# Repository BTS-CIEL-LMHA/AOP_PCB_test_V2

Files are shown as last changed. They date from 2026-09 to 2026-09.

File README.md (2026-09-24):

Ce PCB a été crée pour expérimenter sur différents montages d'amplificateurs opérationnels.

Le principe est d'utiliser 2 cavaliers pour sélectionner le montage utilisé : un pour l'entrée, l'autre pour la sortie.

2 cavaliers à l'entrée et à la sortie du PCB permettent de court-circuiter les condensateurs de liaison pour obtenir une entrée avec offset (indispensable cf ci-dessous)

ATTENTION : il ne faut pas avoir plusieurs cavaliers sur des sorties au risque de court circuit et de destruction des AOP

(on peut avoir plusieurs cavaliers sur les entrées mais c'est déconseillé et cela peut créer des effets indésirables : injection de tension d'un montage à l'autre)

REMARQUE : Les amplis inverseurs et les filtres passe-haut et passe-bande ne sont pas utilisables car l'entrée + est reliée directement ou par une résistance à la masse (au lieu du point milieu de l'alimentation = masse virtuelle)

Les amplis non inverseurs sont utilisable à condition d'avoir un offset (1/2 alimentation) sur le signal d'entrée.

Il est possible assez facilement de modifier les filtres passe-haut et passe-bande en remplaçant la résistance qui va vers la masse par une résistance qui va vers une masse virtuelle.

Pour les amplis inverseur la connexion à la masse étant directe la modification est plus complexe (couper la connexion à la masse du PCB et installer un fil vers la masse virtuelle).

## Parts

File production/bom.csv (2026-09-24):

Designator | Footprint | Quantity | Value | LCSC Part #
C1, C10, C11, C2, C21, C22, C23, C24, C27, C3, C4, C5, C6 | C_Rect_L11.5mm_W3.6mm_P10.00mm_MKT | 13 | C
C20 | C_Radial_D10.0mm_H12.5mm_P5.00mm | 1 | C
C25, C26 | 1206 | 2 | C
J1, J10, J11, J12, J13, J14, J15, J16, J2, J3, J4, J40, J42, J5, J6, J7, J8, J9 | PinHeader_1x02_P2.54mm_Vertical | 18 | Conn_01x02_Pin
J30 | PinHeader_1x02_P2.54mm_Vertical | 1 | Alim
J31 | PinHeader_1x02_P2.54mm_Vertical | 1 | Pile
J32 | BarrelJack_Wuerth_6941xx301002 | 1 | Barrel_Jack_Switch
J41, J43 | BNC_Amphenol_B6252HB-NPP3G-50_Horizontal | 2 | Conn_Coaxial
R1, R10, R11, R2, R3, R4, R5, R6, R7, R8, R9 | R_Axial_DIN0204_L3.6mm_D1.6mm_P7.62mm_Horizontal | 11 | R_US
R12, R13, R14, R15 | 1206 | 4 | R_US
U1, U2, U3, U4, U5 | DIP-8_W7.62mm_Socket_LongPads | 5 | TL081
U6, U7 | SOIC-8_3.9x4.9mm_P1.27mm | 2 | TL081

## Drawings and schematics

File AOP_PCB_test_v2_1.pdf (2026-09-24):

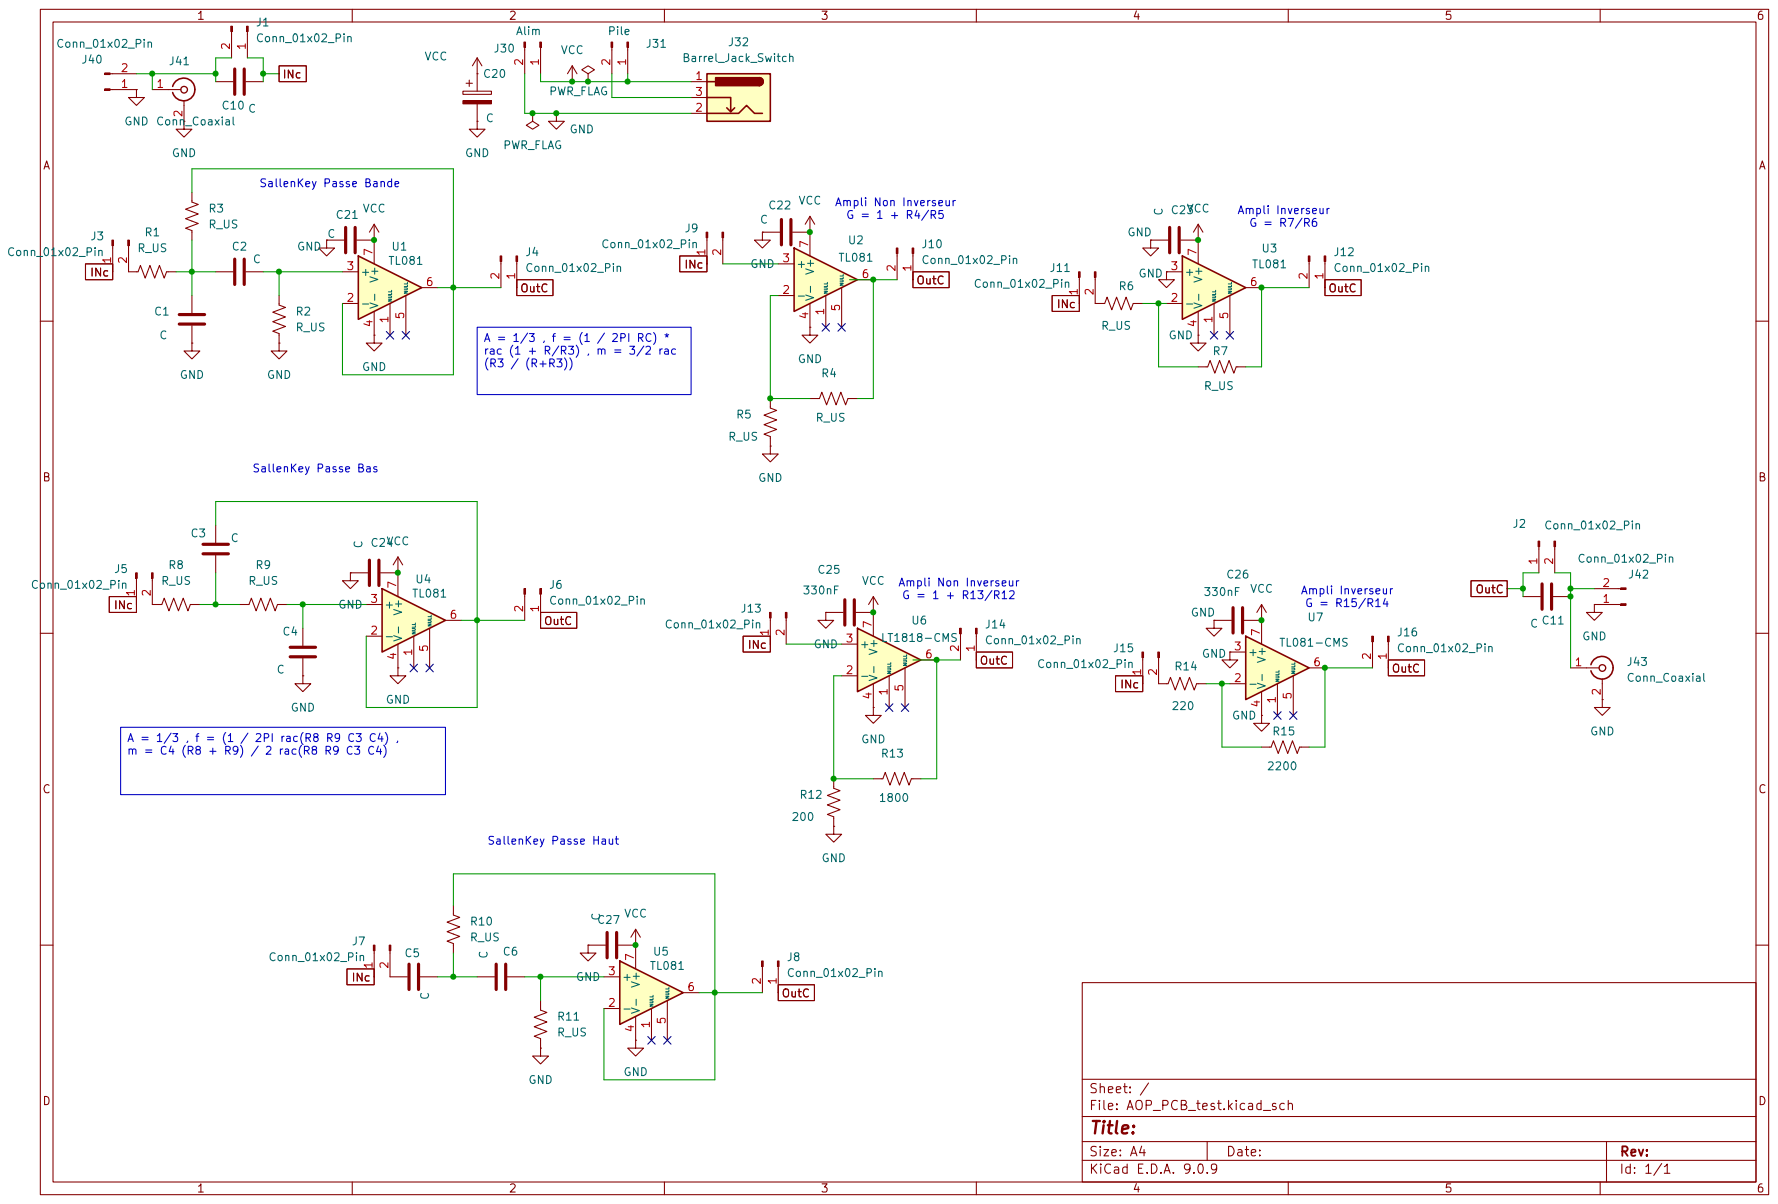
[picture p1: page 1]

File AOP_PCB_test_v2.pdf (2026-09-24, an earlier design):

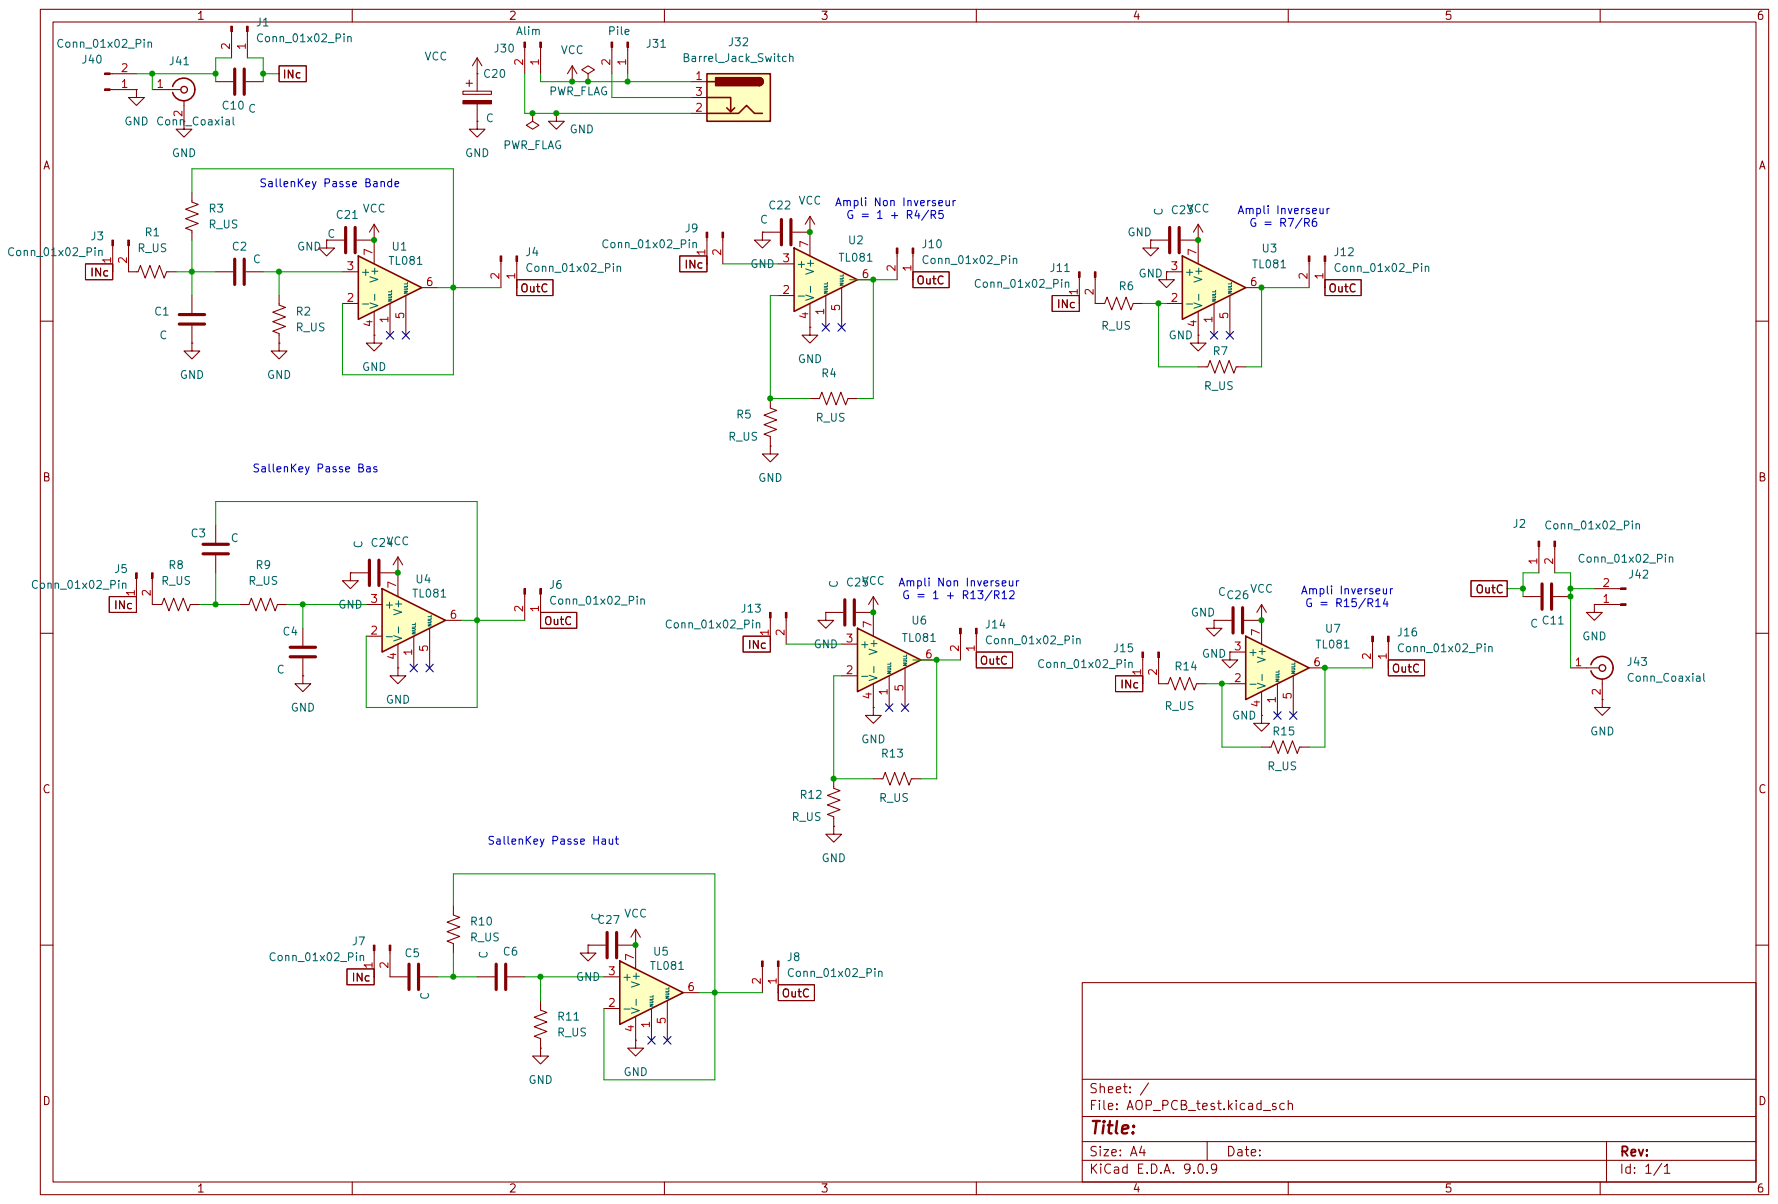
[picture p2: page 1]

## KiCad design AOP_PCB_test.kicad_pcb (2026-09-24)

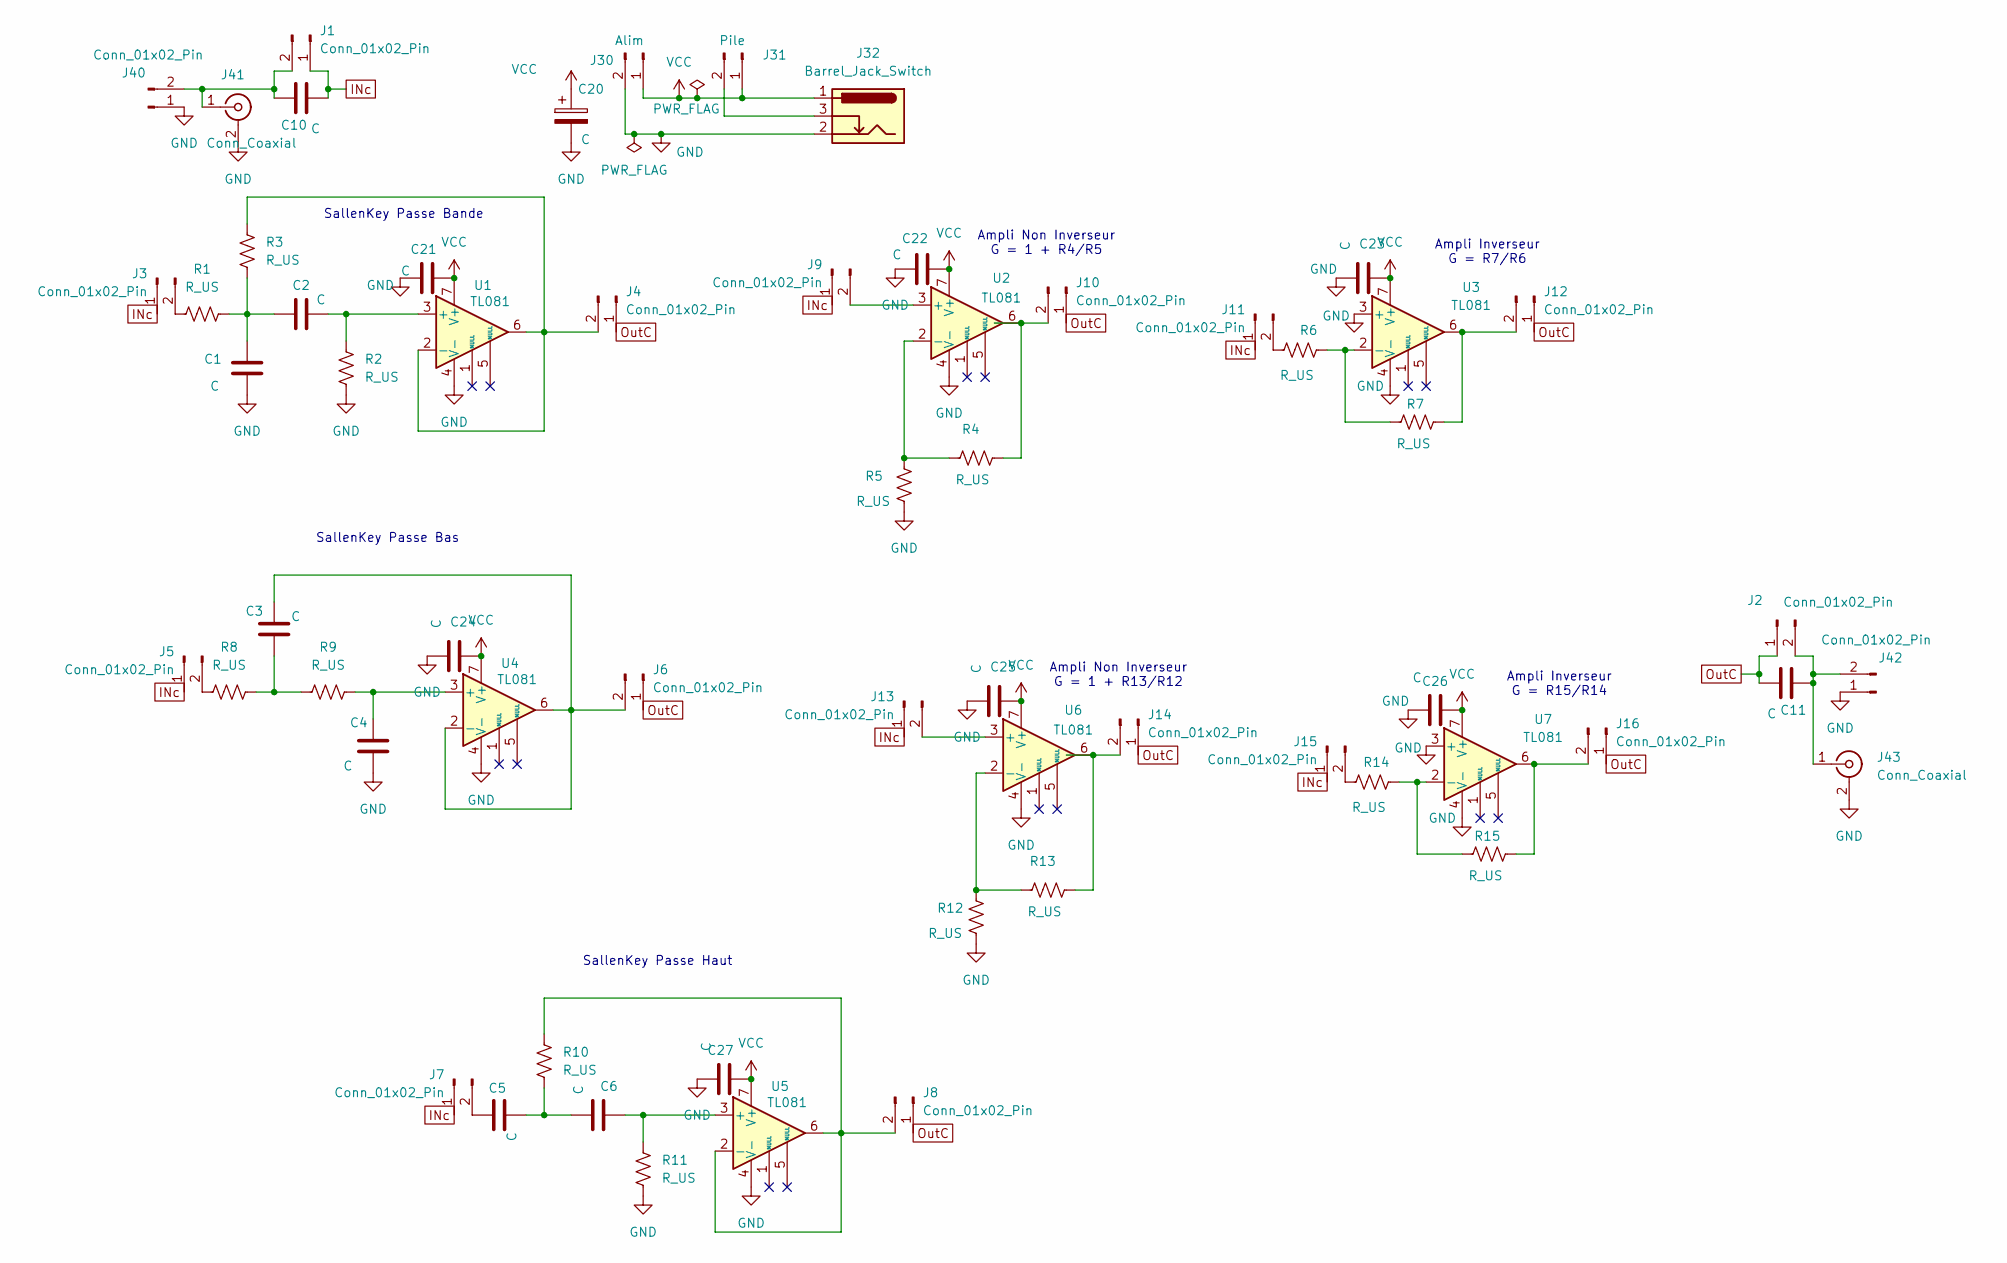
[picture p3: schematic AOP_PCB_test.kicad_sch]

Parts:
C1, C2, C3, C4, C5, C6, C10, C11, C21, C22, C23, C24, C27: C; C_Rect_L11.5mm_W3.6mm_P10.00mm_MKT
C20: C; C_Radial_D10.0mm_H12.5mm_P5.00mm
C25, C26: C; C_1206_3216Metric_Pad1.33x1.80mm_HandSolder
J1, J2, J3, J4, J5, J6, J7, J8, J9, J10, J11, J12, J13, J14, J15, J16, J40, J42: Conn_01x02_Pin; PinHeader_1x02_P2.54mm_Vertical
J30: Alim; PinHeader_1x02_P2.54mm_Vertical
J31: Pile; PinHeader_1x02_P2.54mm_Vertical
J32: Barrel_Jack_Switch; BarrelJack_Wuerth_6941xx301002
J41, J43: Conn_Coaxial; BNC_Amphenol_B6252HB-NPP3G-50_Horizontal
R1, R2, R3, R4, R5, R6, R7, R8, R9, R10, R11: R_US; R_Axial_DIN0204_L3.6mm_D1.6mm_P7.62mm_Horizontal
R12, R13, R14, R15: R_US; R_1206_3216Metric_Pad1.30x1.75mm_HandSolder
U1, U2, U3, U4, U5: TL081; DIP-8_W7.62mm_Socket_LongPads
U6, U7: TL081; SOIC-8_3.9x4.9mm_P1.27mm

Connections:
GND: C1.2, C4.2, C20.2, C21.2, C22.2, C23.2, C24.2, C25.2, C26.2, C27.2, J30.2, J32.2, J40.1, J41.2 (Ext), J42.1, J43.2 (Ext), R2.1, R5.1, R11.2, R12.1, U1.4 (V-), U2.4 (V-), U3.3 (+), U3.4 (V-), U4.4 (V-), U5.4 (V-), U6.4 (V-), U7.3 (+), U7.4 (V-)
INc: C10.1, J1.1, J3.1, J5.1, J7.1, J9.1, J11.1, J13.1, J15.1
unnamed: C1.1, C2.2, R1.1, R3.2
unnamed: C3.2, R8.1, R9.2
unnamed: C5.1, C6.2, R10.1
unnamed: C10.2, J1.2, J40.2, J41.1 (In)
unnamed: C11.2, J2.2, J42.2, J43.1 (In)
unnamed: J3.2, R1.2
unnamed: J4.2, R3.1, U1.2 (-), U1.6
unnamed: J5.2, R8.2
unnamed: C3.1, J6.2, U4.2 (-), U4.6
unnamed: C5.2, J7.2
unnamed: J8.2, R10.2, U5.2 (-), U5.6
unnamed: J9.2, U2.3 (+)
unnamed: J10.2, R4.2, U2.6
unnamed: J11.2, R6.2
unnamed: J12.2, R7.2, U3.6
unnamed: J13.2, U6.3 (+)
unnamed: J14.2, R13.2, U6.6
unnamed: J15.2, R14.2
unnamed: J16.2, R15.2, U7.6
unnamed: J31.2, J32.3
unnamed: C2.1, R2.2, U1.3 (+)
unnamed: R4.1, R5.2, U2.2 (-)
unnamed: R6.1, R7.1, U3.2 (-)
unnamed: C4.1, R9.1, U4.3 (+)
unnamed: C6.1, R11.1, U5.3 (+)
unnamed: R12.2, R13.1, U6.2 (-)
unnamed: R14.1, R15.1, U7.2 (-)
OutC: C11.1, J2.1, J4.1, J6.1, J8.1, J10.1, J12.1, J14.1, J16.1
VCC: C20.1, C21.1, C22.1, C23.1, C24.1, C25.1, C26.1, C27.1, J30.1, J31.1, J32.1, U1.7 (V+), U2.7 (V+), U3.7 (V+), U4.7 (V+), U5.7 (V+), U6.7 (V+), U7.7 (V+)

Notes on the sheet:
Ampli Non Inverseur G = 1 + R4/R5
SallenKey Passe Bas
Ampli Non Inverseur G = 1 + R13/R12
Ampli Inverseur G = R15/R14
SallenKey Passe Haut
Ampli Inverseur G = R7/R6
SallenKey Passe Bande

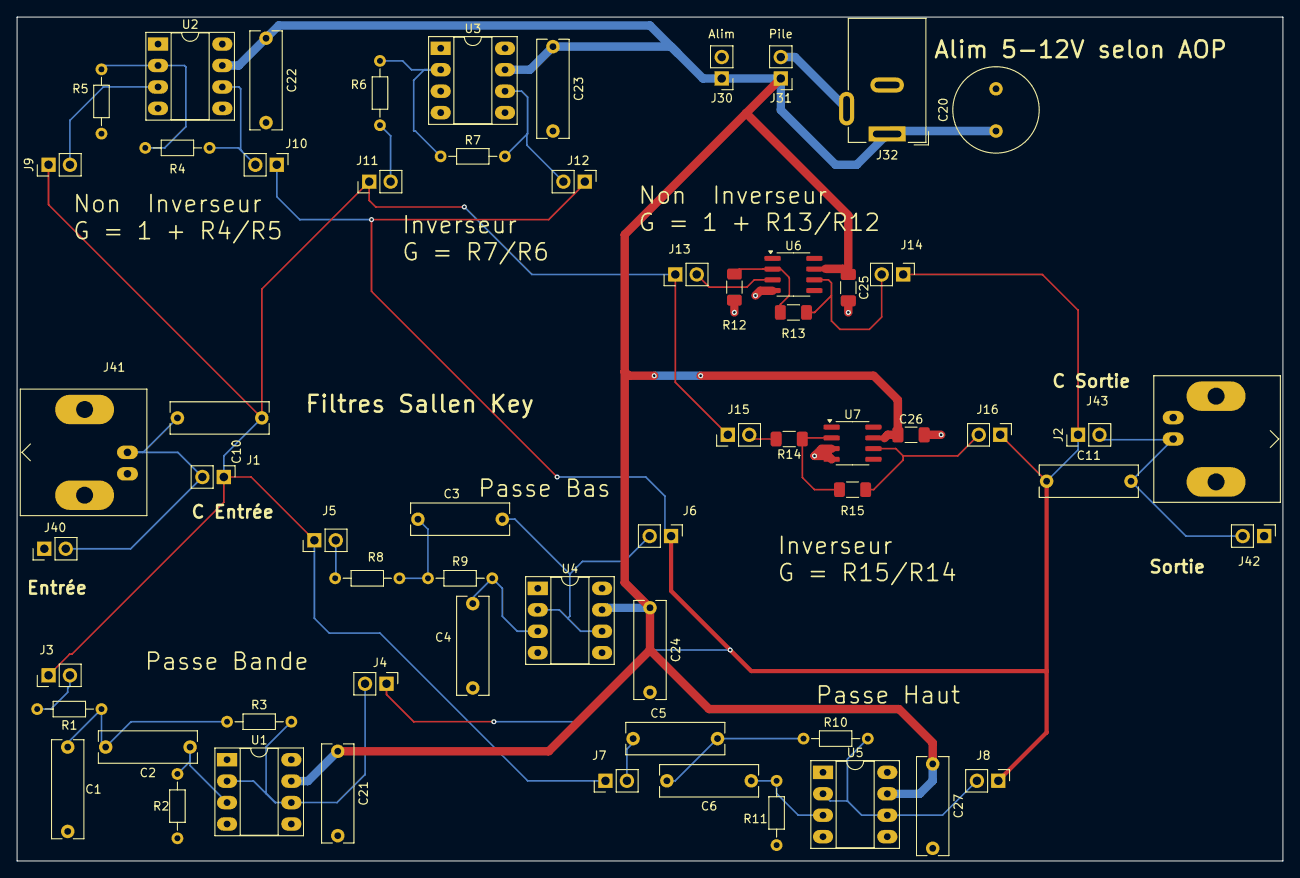
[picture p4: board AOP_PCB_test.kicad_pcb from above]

Board: 2 copper layers, 150.0 x 100.0 mm, 61 parts (0 on the bottom side), 31 nets.

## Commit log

2026-09-24 Add PCB description for operational amplifier experiments
    Added details about the PCB for operational amplifier experiments.
2026-09-24 ajout des formules filtres et quelques valeurs
    [AOP_PCB_test.kicad_sch]
2026-09-24 Fix typo in README.md regarding PCB description
    Corrected a typo in the description of the PCB functionality.
